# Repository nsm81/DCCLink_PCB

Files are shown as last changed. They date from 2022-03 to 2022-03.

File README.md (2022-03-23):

# DCCLink_PCB

The DCCLink board connects the DCC track signal to an Arduino. It also provides a regulated 5V supply from the track. It does not provide DCC ACK support for PoM (Programming on the main).

The board is designed and made in KiCad 6.0.

I reccomend using the AP_DCC_Library written by Aiko Pras.





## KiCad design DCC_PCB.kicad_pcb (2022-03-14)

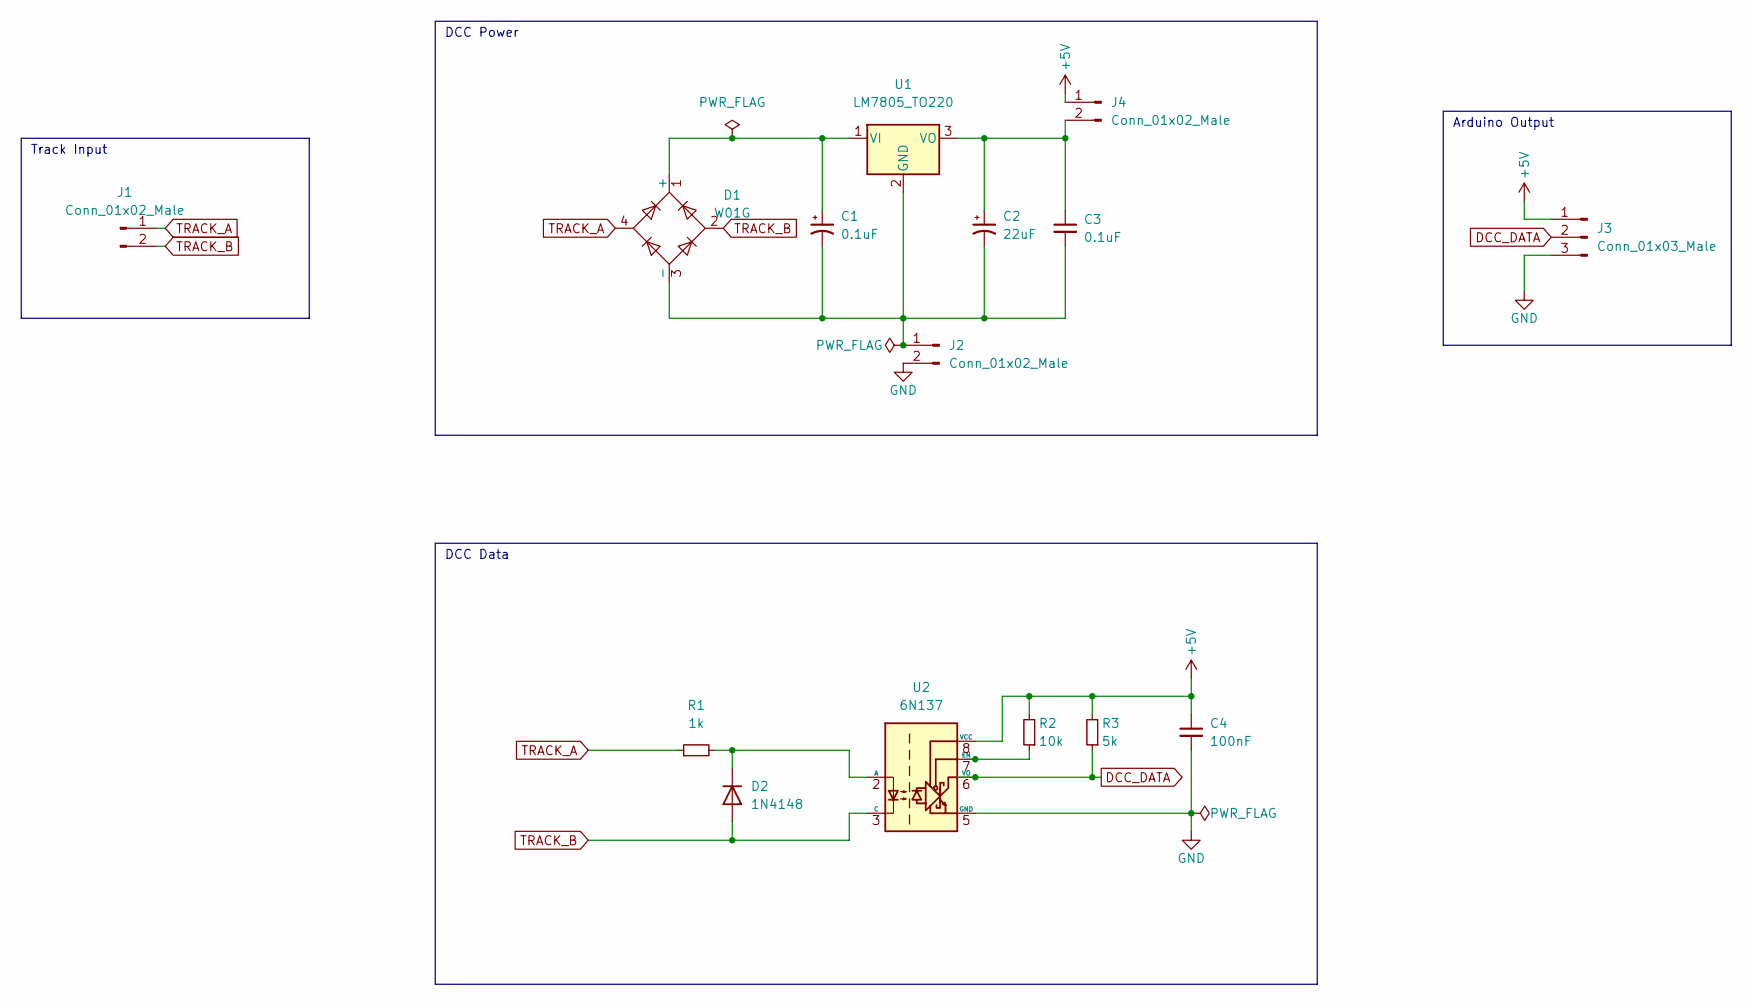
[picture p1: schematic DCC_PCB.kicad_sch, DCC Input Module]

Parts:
C1: 0.1uF; CP_Radial_D5.0mm_P2.00mm
C2: 22uF; CP_Radial_D4.0mm_P1.50mm
C3: 0.1uF; C_Disc_D5.0mm_W2.5mm_P5.00mm
C4: 100nF; C_Disc_D5.0mm_W2.5mm_P5.00mm
D1: W01G; Diode_Bridge_Round_D9.8mm
D2: 1N4148; D_DO-35_SOD27_P2.54mm_Vertical_AnodeUp
J1, J2, J4: Conn_01x02_Male; PinHeader_1x02_P2.54mm_Vertical
J3: Conn_01x03_Male; PinHeader_1x03_P2.54mm_Vertical
R1: 1k; R_Axial_DIN0204_L3.6mm_D1.6mm_P1.90mm_Vertical
R2: 10k; R_Axial_DIN0204_L3.6mm_D1.6mm_P1.90mm_Vertical
R3: 5k; R_Axial_DIN0204_L3.6mm_D1.6mm_P1.90mm_Vertical
U1: LM7805_TO220; TO-220-3_Vertical
U2: 6N137; DIP-8_W7.62mm

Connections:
+5V: C4.1, J3.1, J4.1, R2.2, R3.2, U2.8 (VCC)
DCC_DATA: J3.2, R3.1, U2.6 (VO)
GND: C4.2, J2.2, J3.3, U2.5 (GND)
unnamed: C1.1, D1.1 (+), U1.1 (VI)
unnamed: C1.2, C2.2, C3.2, D1.3 (-), J2.1, U1.2 (GND)
unnamed: C2.1, C3.1, J4.2, U1.3 (VO)
unnamed: D2.1 (K), R1.2, U2.2 (A)
unnamed: R2.1, U2.7 (EN)
TRACK_A: D1.4, J1.1, R1.1
TRACK_B: D1.2, D2.2 (A), J1.2, U2.3 (C)

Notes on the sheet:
DCC Power
Arduino Output
DCC Data
Track Input

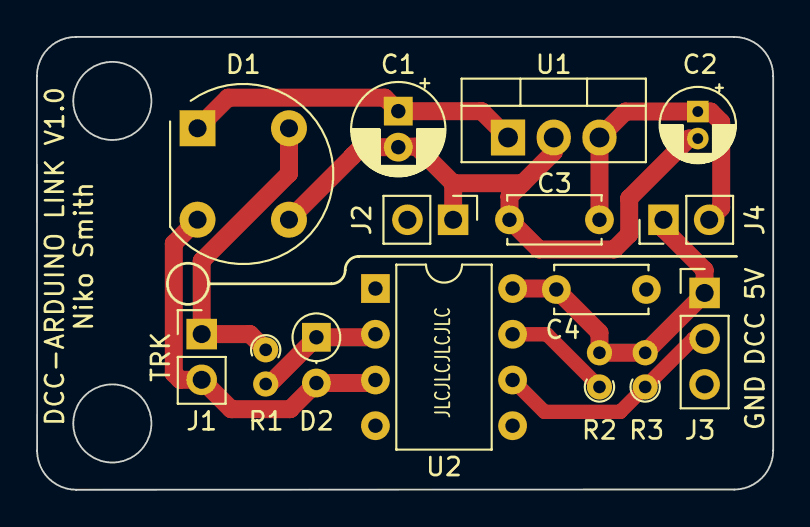
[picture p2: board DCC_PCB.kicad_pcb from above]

Board: 2 copper layers, 40.9 x 25.2 mm, 15 parts (0 on the bottom side), 10 nets.
